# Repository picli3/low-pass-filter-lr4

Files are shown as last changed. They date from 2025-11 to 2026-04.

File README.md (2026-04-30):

# low-pass-filter-lr4

Filtro pasa bajos activo Linkwitz-Riley de cuarto orden, pensado para subwoofer o cruces activos en sistemas de audio.

## Qué incluye
- esquemáticos o archivos de diseño en KiCad
- PCB o documentación asociada
- base reutilizable para análisis, fabricación o mejora del proyecto

## Propósito general
Este repositorio busca concentrar el diseño de hardware del proyecto en un formato editable y reutilizable, facilitando pruebas, documentación y futuras iteraciones del circuito.

## Lista de materiales (BOM)

| referencia | valor | footprint |
| --- | --- | --- |
| C1 | 22nF | `Capacitor_THT:C_Rect_L7.2mm_W2.5mm_P5.00mm_FKS2_FKP2_MKS2_MKP2` |
| C2 | 22nF | `Capacitor_THT:C_Rect_L7.2mm_W2.5mm_P5.00mm_FKS2_FKP2_MKS2_MKP2` |
| C3 | 22nF | `Capacitor_THT:C_Rect_L7.2mm_W2.5mm_P5.00mm_FKS2_FKP2_MKS2_MKP2` |
| C4 | 22nF | `Capacitor_THT:C_Rect_L7.2mm_W2.5mm_P5.00mm_FKS2_FKP2_MKS2_MKP2` |
| C5 | 22nF | `Capacitor_THT:C_Rect_L7.2mm_W2.5mm_P5.00mm_FKS2_FKP2_MKS2_MKP2` |
| C6 | 22nF | `Capacitor_THT:C_Rect_L7.2mm_W2.5mm_P5.00mm_FKS2_FKP2_MKS2_MKP2` |
| C7 | 100nF | `Capacitor_THT:C_Disc_D5.0mm_W2.5mm_P2.50mm` |
| C8 | 100nF | `Capacitor_THT:C_Disc_D5.0mm_W2.5mm_P2.50mm` |
| J1 | Conn_01x03 | `Connector_PinHeader_2.54mm:PinHeader_1x03_P2.54mm_Vertical` |
| J2 | Conn_01x02 | `Connector_PinHeader_2.54mm:PinHeader_1x02_P2.54mm_Vertical` |
| J3 | Conn_01x02 | `Connector_PinHeader_2.54mm:PinHeader_1x02_P2.54mm_Vertical` |
| R1 | 33k | `Resistor_THT:R_Axial_DIN0207_L6.3mm_D2.5mm_P10.16mm_Horizontal` |
| R3 | 33k | `Resistor_THT:R_Axial_DIN0207_L6.3mm_D2.5mm_P10.16mm_Horizontal` |
| R5 | 33k | `Resistor_THT:R_Axial_DIN0207_L6.3mm_D2.5mm_P10.16mm_Horizontal` |
| R7 | 33k | `Resistor_THT:R_Axial_DIN0207_L6.3mm_D2.5mm_P10.16mm_Horizontal` |
| U1 | NE5532 | `Package_DIP:DIP-8_W7.62mm_LongPads` |

## Vista del proyecto

### Render 3D del PCB
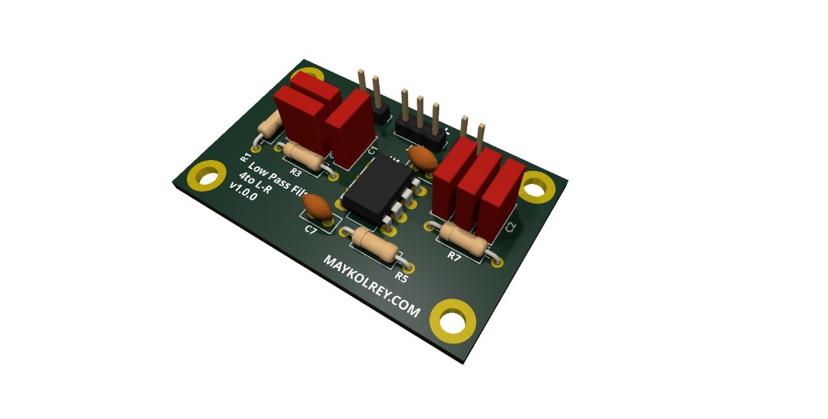
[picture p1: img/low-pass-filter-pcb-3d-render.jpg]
Render 3D del PCB


### Render del módulo y layout del PCB
<p align="center">
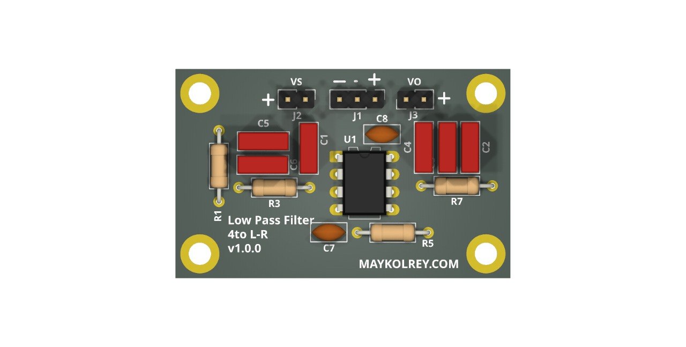
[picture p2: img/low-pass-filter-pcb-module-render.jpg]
Render del módulo ensamblado
  
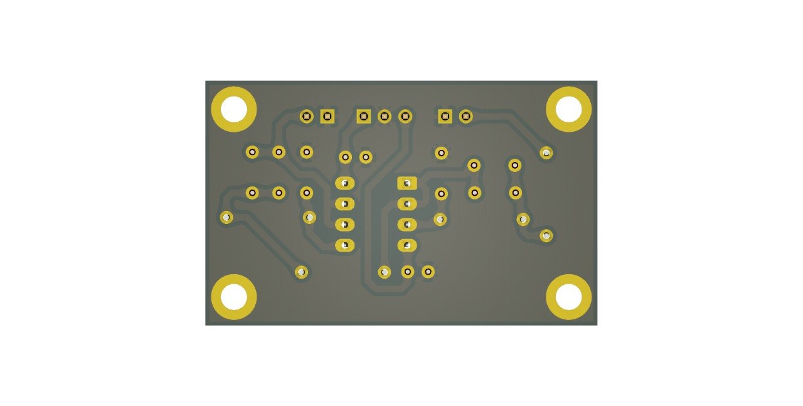
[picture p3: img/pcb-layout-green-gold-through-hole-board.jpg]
Layout del PCB
  
</p>

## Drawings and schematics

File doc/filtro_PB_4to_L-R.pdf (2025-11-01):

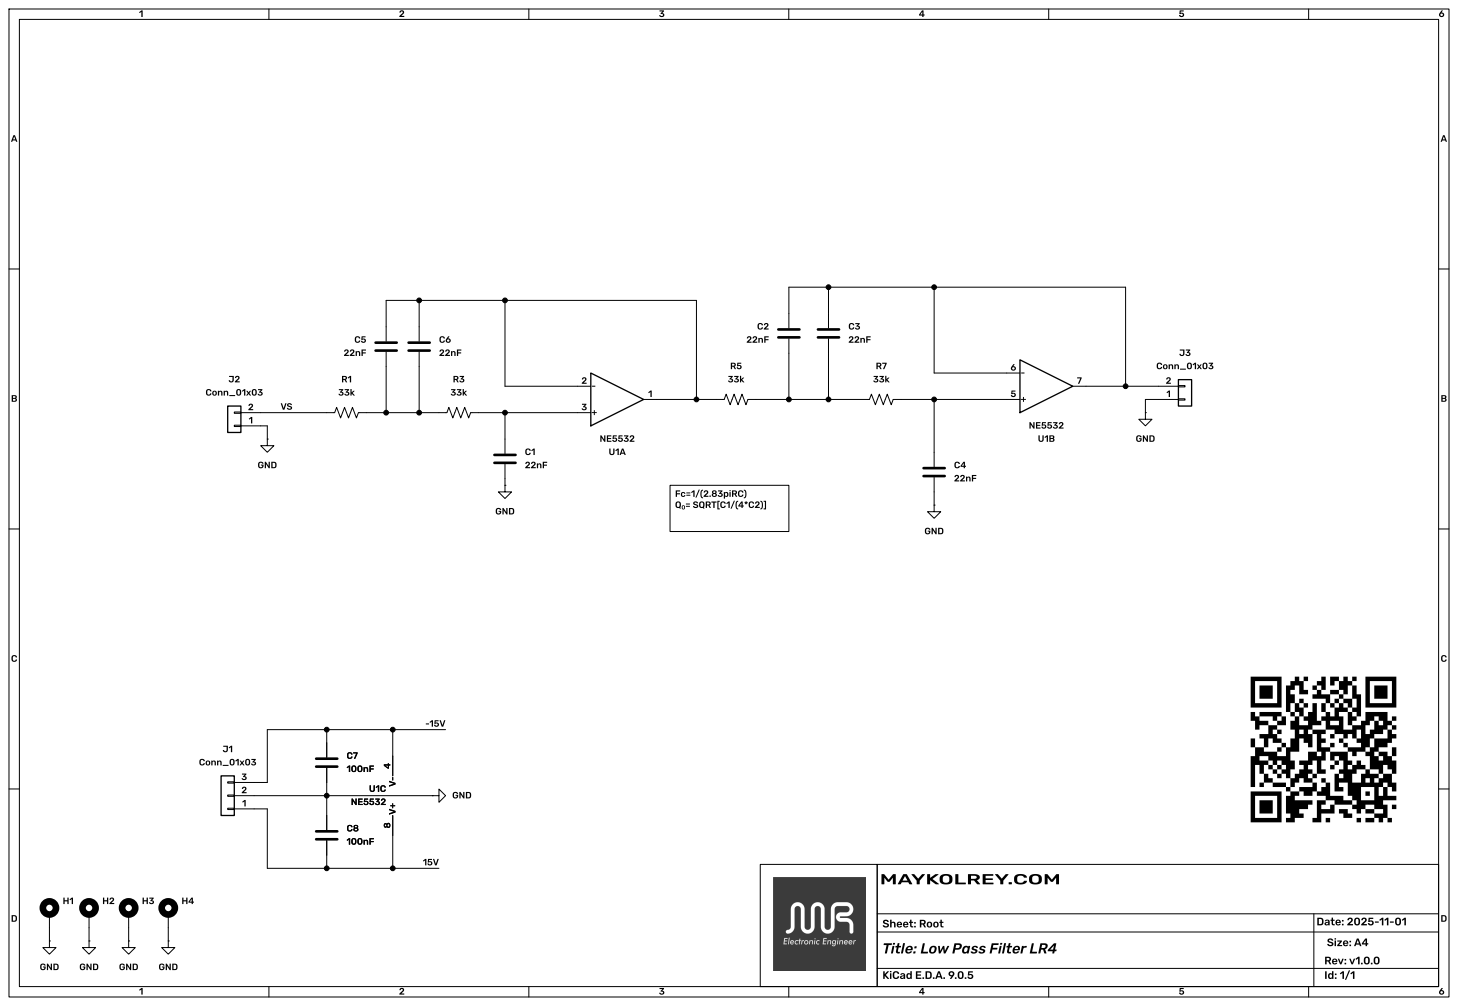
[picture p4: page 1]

Sheet: Root MAYKOLREY.COM

Id: 1/1 Title: Low Pass Filter LR4

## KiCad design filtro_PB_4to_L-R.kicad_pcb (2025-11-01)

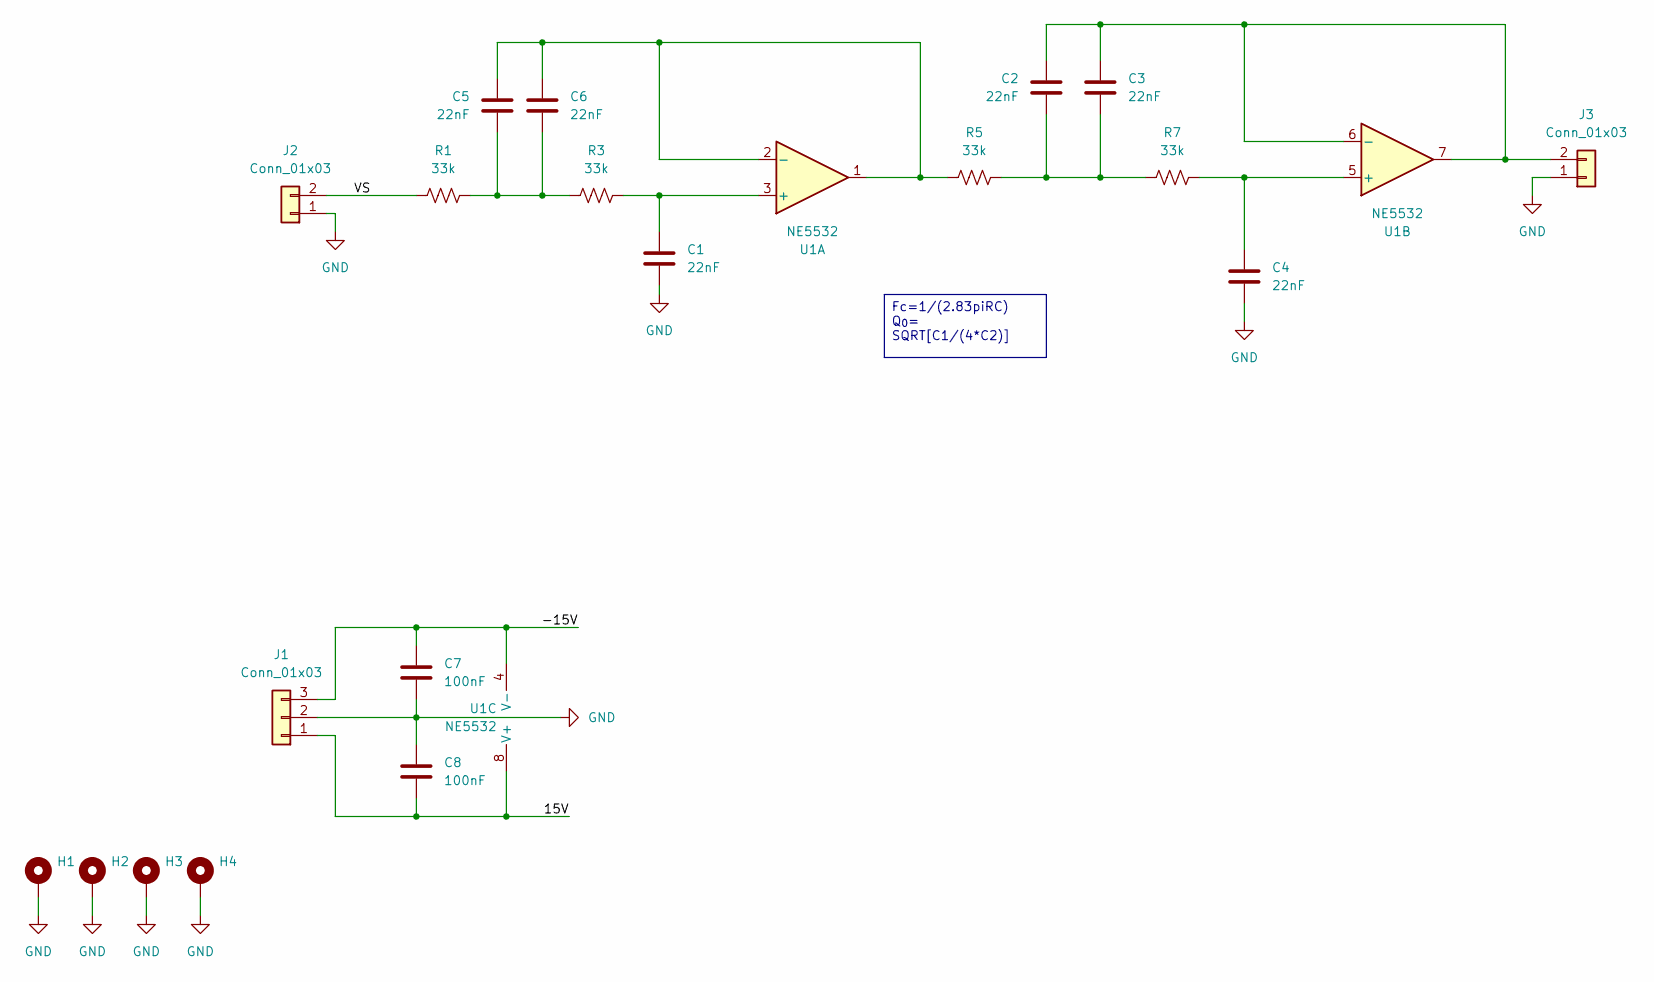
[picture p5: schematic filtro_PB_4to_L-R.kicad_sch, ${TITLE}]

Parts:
C1, C2, C3, C4, C5, C6: 22nF; C_Rect_L7.2mm_W2.5mm_P5.00mm_FKS2_FKP2_MKS2_MKP2
C7, C8: 100nF; C_Disc_D5.0mm_W2.5mm_P2.50mm
H1, H2, H3, H4: MountingHole_Pad; MountingHole_3.2mm_M3_DIN965_Pad
J1: Conn_01x03; PinHeader_1x03_P2.54mm_Vertical
J2, J3: Conn_01x03; PinHeader_1x02_P2.54mm_Vertical
R1, R3, R5, R7: 33k; R_Axial_DIN0207_L6.3mm_D2.5mm_P10.16mm_Horizontal
U1: NE5532; DIP-8_W7.62mm_LongPads

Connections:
/15V: C8.1, J1.1, U1.8 (V+)
/-15V: C7.2, J1.3, U1.4 (V-)
/VS: J2.2, R1.2
GND: C1.1, C4.1, C7.1, C8.2, H1.1, H2.1, H3.1, H4.1, J1.2, J2.1, J3.1
unnamed: C2.1, C3.1, R5.1, R7.2
unnamed: C5.1, C6.1, R1.1, R3.2
unnamed: C2.2, C3.2, J3.2, U1.6 (-), U1.7
unnamed: C1.2, R3.1, U1.3 (+)
unnamed: C5.2, C6.2, R5.2, U1.1, U1.2 (-)
unnamed: C4.2, R7.1, U1.5 (+)

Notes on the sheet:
Fc=1/(2.83piRC) Q_{0}= SQRT[C1/(4*C2)]

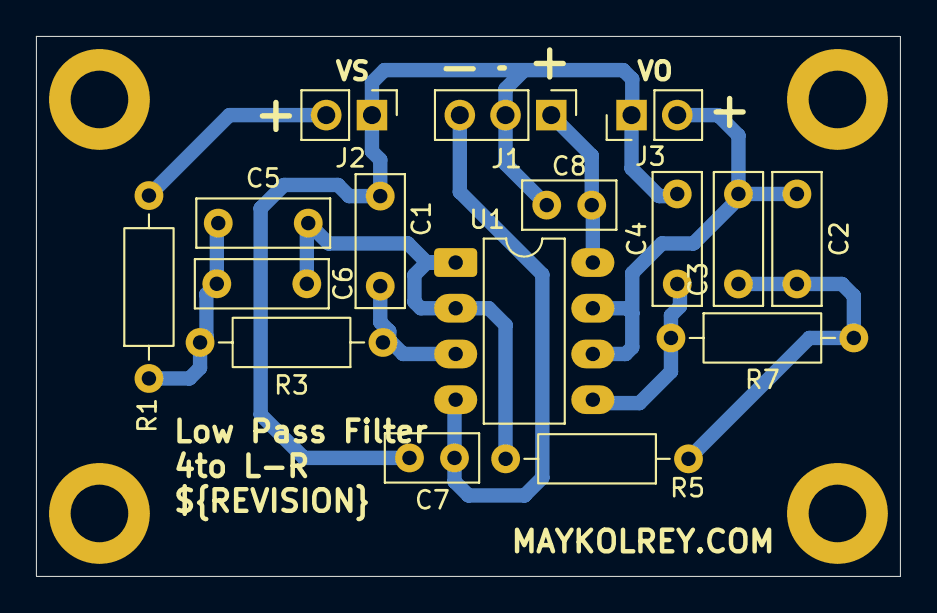
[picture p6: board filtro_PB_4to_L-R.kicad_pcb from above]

Board: 2 copper layers, 48.0 x 30.0 mm, 20 parts (0 on the bottom side), 10 nets.

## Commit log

2025-11-01 primer commit
    [filtro_PB_4to_L-R.kicad_pcb, filtro_PB_4to_L-R.kicad_sch]
2025-11-01 agregando QR de documentacion
    [filtro_PB_4to_L-R.kicad_pcb, filtro_PB_4to_L-R.kicad_sch]
2026-04-30 docs: add project BOM to README
2026-04-30 Fix J2 and J3 connector values
    [filtro_PB_4to_L-R.kicad_sch]
